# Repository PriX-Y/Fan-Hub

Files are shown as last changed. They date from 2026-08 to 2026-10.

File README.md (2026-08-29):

# Fan-Hub
**RP2040 PWM Fan Controller for x4 fan**
Zrzut ekranu 2026-08-18 223545
i made becuse this summer in europa is so hot: 43c but i didt have fan what have enough control for me so i made that, becuse my so bad soldring skill i make this full THT

# Programs
**Kicad - 10.1**

**Autodesk Fusion**

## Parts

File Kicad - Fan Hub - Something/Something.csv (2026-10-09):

Id | Oznaczenie | Footprint | Liczba | Oznaczenie | Dostawca i numer artykułu
1 | A1 | raspberry_pi_pico_THT | 1 | Raspberry_Pi_Pico_THT
2 | C1, C6, C9 | C_Disc_D5.0mm_W2.5mm_P2.50mm | 3 | 0.1uF
3 | C2, C5, C8 | C_Disc_D5.0mm_W2.5mm_P2.50mm | 3 | 1uF
4 | C3, C4, C7 | C_Disc_D5.0mm_W2.5mm_P2.50mm | 3 | 10uF
5 | D1, D6 | D_DO-41_SOD81_P7.62mm_Horizontal | 2 | 1N5818
6 | D2, D3, D4, D5 | D_DO-35_SOD27_P7.62mm_Horizontal | 4 | 1N4148
7 | J1 | BarrelJack_SwitchcraftConxall_RAPC10U_Horizontal | 1 | Barrel_Jack
8 | L1 | L_Axial_L5.3mm_D2.2mm_P10.16mm_Horizontal_Vishay_IM-1 | 1 | 100uH
9 | M1, M2, M3, M4 | FanPinHeader_1x04_P2.54mm_Vertical | 4 | Fan_4pin
10 | R1, R2, R3 | R_Axial_DIN0207_L6.3mm_D2.5mm_P10.16mm_Horizontal | 3 | 100k
11 | R4, R5, R6, R7, R8, R9 | R_Axial_DIN0207_L6.3mm_D2.5mm_P10.16mm_Horizontal | 6 | 10k
12 | SW5, SW6, SW7, SW8 | RotaryEncoder_Bourns_Horizontal_PEC12R-2x17F-Sxxxx | 4 | RotaryEncoder_Switch
13 | U1 | DIP-8_W7.62mm | 1 | ADP1108AN-12
14 | U2 | Converter_DCDC_TRACO_TSR-1_THT | 1 | TSR_1-24150
15 | U3 | ER_OLEDM0.91_1x-I2C | 1 | ER_OLEDM0.91_1x-I2C
16 | U4 | TO-92_Inline | 1 | LM35-LP

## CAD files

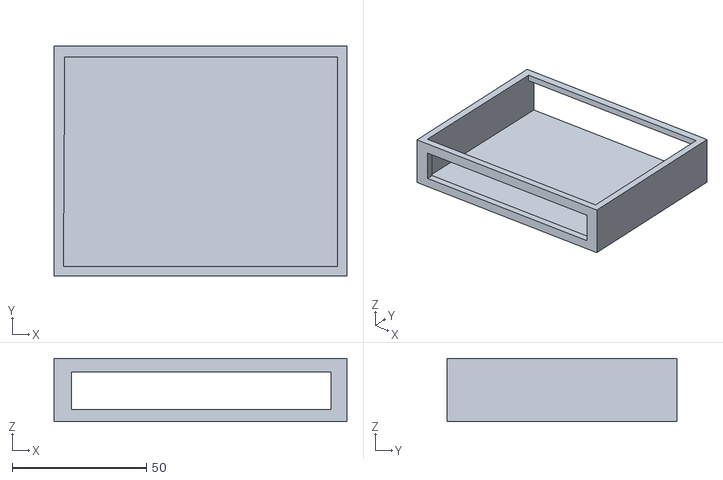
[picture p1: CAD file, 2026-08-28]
Case/HUB-CASE-DOWN.stl
109.0 x 85.5 x 23.5

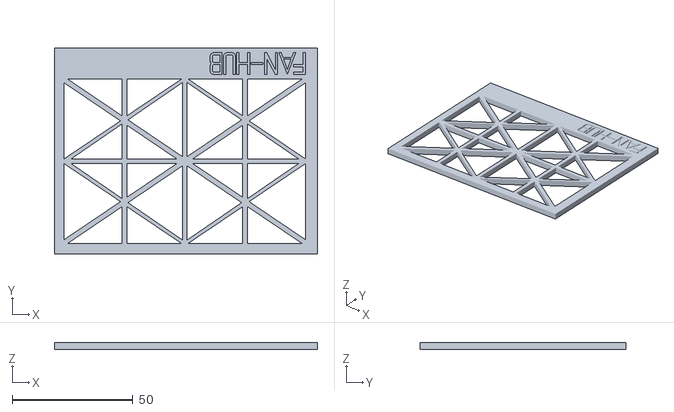
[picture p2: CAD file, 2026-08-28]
Case/HUB-CASE-TOP.stl
109.0 x 85.5 x 3.00

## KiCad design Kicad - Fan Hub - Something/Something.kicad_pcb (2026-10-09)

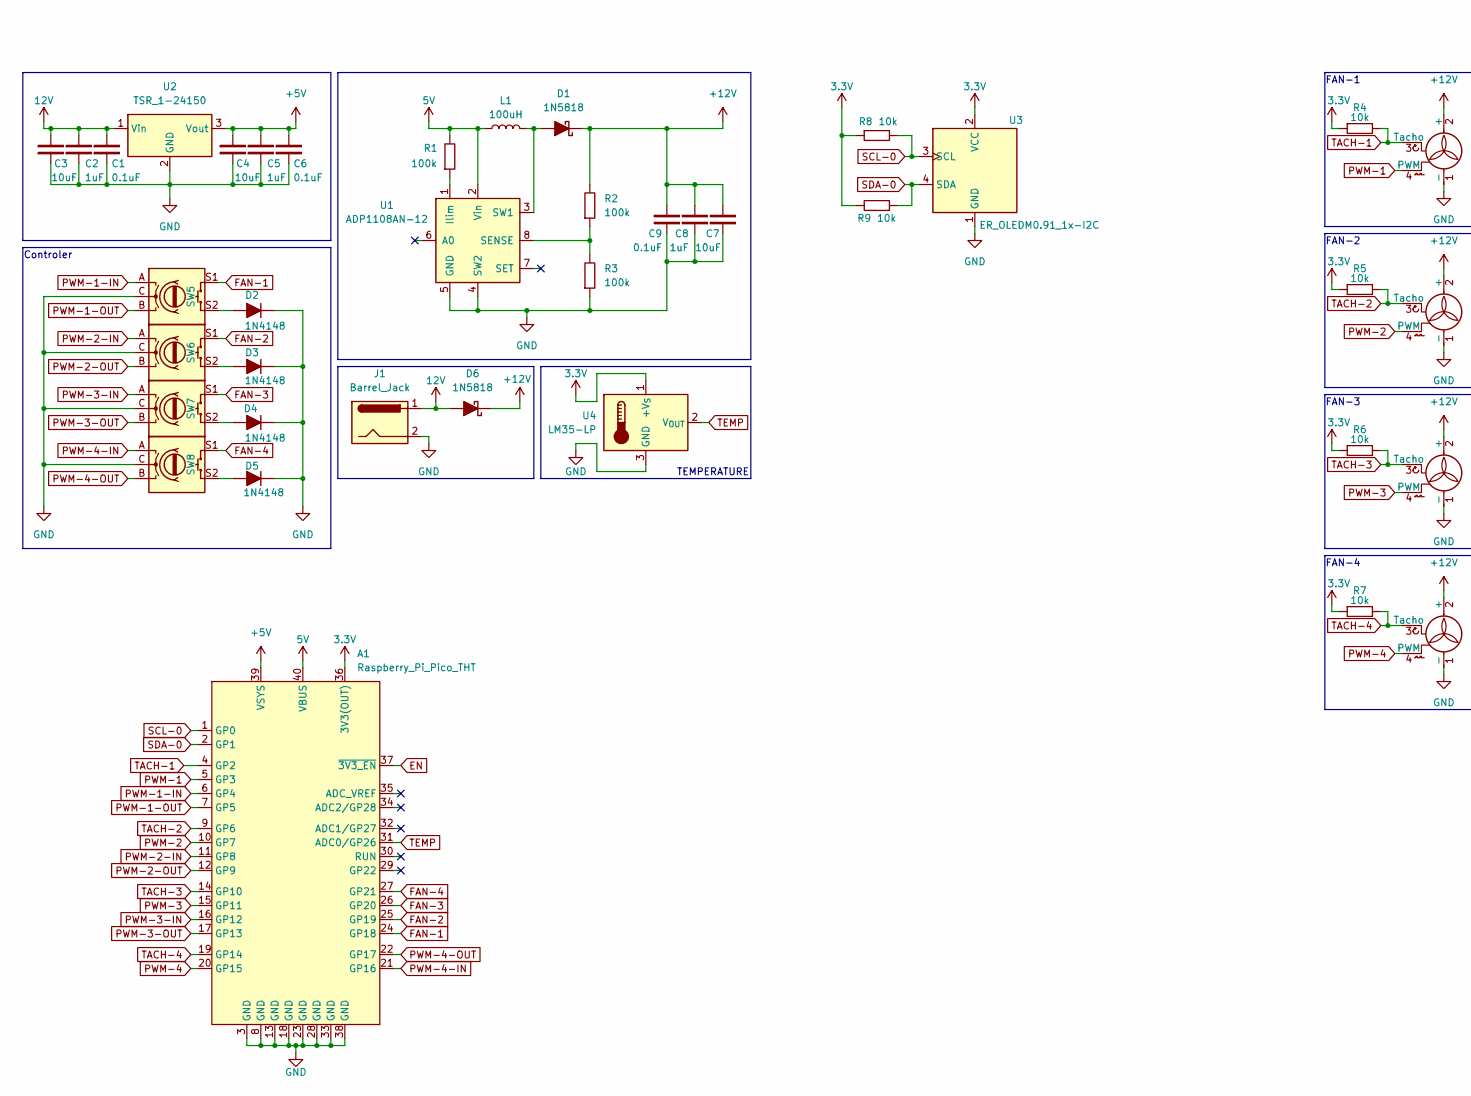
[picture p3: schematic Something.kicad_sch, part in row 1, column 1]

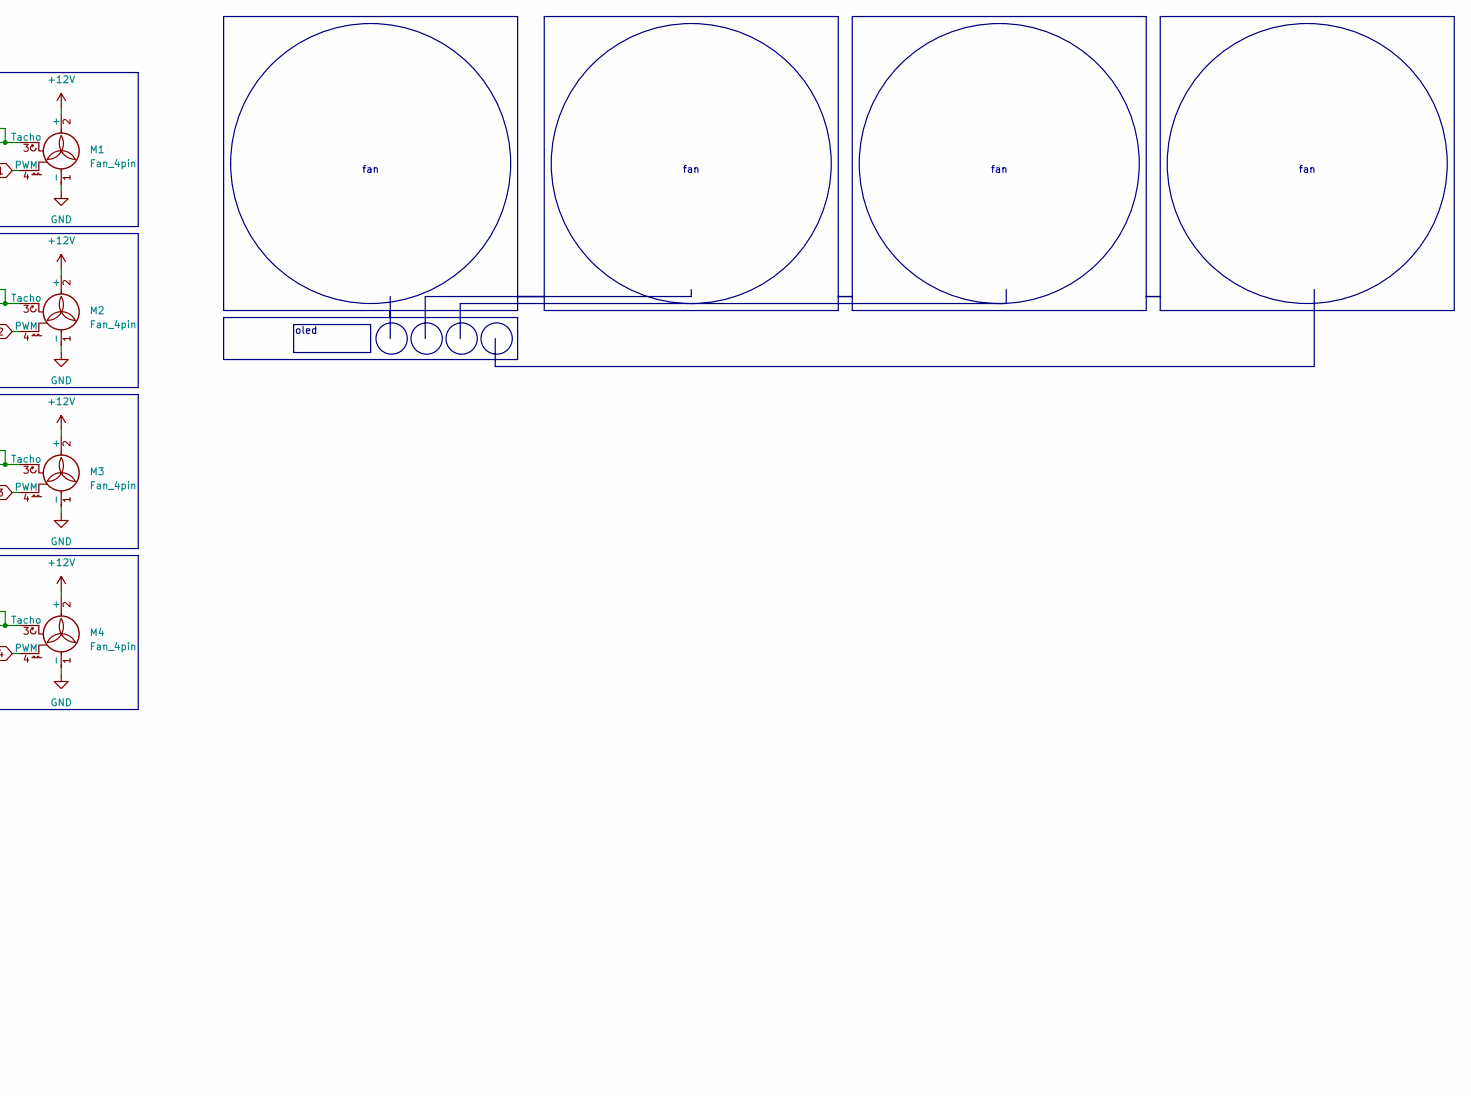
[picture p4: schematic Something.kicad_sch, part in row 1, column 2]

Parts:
A1: Raspberry_Pi_Pico_THT; raspberry_pi_pico_THT
C1, C6, C9: 0.1uF; C_Disc_D5.0mm_W2.5mm_P2.50mm
C2, C5, C8: 1uF; C_Disc_D5.0mm_W2.5mm_P2.50mm
C3, C4, C7: 10uF; C_Disc_D5.0mm_W2.5mm_P2.50mm
D1, D6: 1N5818; D_DO-41_SOD81_P7.62mm_Horizontal
D2, D3, D4, D5: 1N4148; D_DO-35_SOD27_P7.62mm_Horizontal
J1: Barrel_Jack; BarrelJack_SwitchcraftConxall_RAPC10U_Horizontal
L1: 100uH; L_Axial_L5.3mm_D2.2mm_P10.16mm_Horizontal_Vishay_IM-1
M1, M2, M3, M4: Fan_4pin; FanPinHeader_1x04_P2.54mm_Vertical
R1, R2, R3: 100k; R_Axial_DIN0207_L6.3mm_D2.5mm_P10.16mm_Horizontal
R4, R5, R6, R7, R8, R9: 10k; R_Axial_DIN0207_L6.3mm_D2.5mm_P10.16mm_Horizontal
SW5, SW6, SW7, SW8: RotaryEncoder_Switch; RotaryEncoder_Bourns_Horizontal_PEC12R-2x17F-Sxxxx
U1: ADP1108AN-12; DIP-8_W7.62mm
U2: TSR_1-24150; Converter_DCDC_TRACO_TSR-1_THT
U3: ER_OLEDM0.91_1x-I2C
U4: LM35-LP; TO-92_Inline

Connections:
3.3V: A1.36 (3V3(OUT)), R4.1, R5.1, R6.1, R7.1, R8.1, R9.2, U3.2 (VCC), U4.1 (+V_{S})
5V: A1.40 (VBUS), L1.1, R1.2, U1.2 (Vin)
12V: C1.2, C2.2, C3.2, D6.2 (A), J1.1, U2.1 (Vin)
+5V: A1.39 (VSYS), C4.2, C5.2, C6.2, U2.3 (Vout)
+12V: C7.2, C8.2, C9.2, D1.1 (K), D6.1 (K), M1.2 (+), M2.2 (+), M3.2 (+), M4.2 (+), R2.2
EN: A1.37 (~3V3_EN)
FAN-1: A1.24 (GP18), SW5.S1
FAN-2: A1.25 (GP19), SW6.S1
FAN-3: A1.26 (GP20), SW7.S1
FAN-4: A1.27 (GP21), SW8.S1
GND: A1.3 (GND), A1.8 (GND), A1.13 (GND), A1.18 (GND), A1.23 (GND), A1.28 (GND), A1.33 (GND), A1.38 (GND), C1.1, C2.1, C3.1, C4.1, C5.1, C6.1, C7.1, C8.1, C9.1, D2.1 (K), D3.1 (K), D4.1 (K), D5.1 (K), J1.2, M1.1 (-), M2.1 (-), M3.1 (-), M4.1 (-), R3.1, SW5.C, SW5.SH, SW6.C, SW7.C, SW8.C, U1.4 (SW2), U1.5 (GND), U2.2 (GND), U3.1 (GND), U4.3 (GND)
unnamed: D1.2 (A), L1.2, U1.3 (SW1)
unnamed: D2.2 (A), SW5.S2
unnamed: D3.2 (A), SW6.S2
unnamed: D4.2 (A), SW7.S2
unnamed: D5.2 (A), SW8.S2
unnamed: R1.1, U1.1 (Ilim)
unnamed: R2.1, R3.2, U1.8 (SENSE)
PWM-1: A1.5 (GP3), M1.4 (PWM)
PWM-1-IN: A1.6 (GP4), SW5.A
PWM-1-OUT: A1.7 (GP5), SW5.B
PWM-2: A1.10 (GP7), M2.4 (PWM)
PWM-2-IN: A1.11 (GP8), SW6.A
PWM-2-OUT: A1.12 (GP9), SW6.B
PWM-3: A1.15 (GP11), M3.4 (PWM)
PWM-3-IN: A1.16 (GP12), SW7.A
PWM-3-OUT: A1.17 (GP13), SW7.B
PWM-4: A1.20 (GP15), M4.4 (PWM)
PWM-4-IN: A1.21 (GP16), SW8.A
PWM-4-OUT: A1.22 (GP17), SW8.B
SCL-0: A1.1 (GP0), R8.2, U3.3 (SCL)
SDA-0: A1.2 (GP1), R9.1, U3.4 (SDA)
TACH-1: A1.4 (GP2), M1.3 (Tacho), R4.2
TACH-2: A1.9 (GP6), M2.3 (Tacho), R5.2
TACH-3: A1.14 (GP10), M3.3 (Tacho), R6.2
TACH-4: A1.19 (GP14), M4.3 (Tacho), R7.2
TEMP: A1.31 (ADC0/GP26), U4.2 (V_{OUT})

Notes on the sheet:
fan
Controler
FAN-4
FAN-3
TEMPERATURE
oled
FAN-1
FAN-2

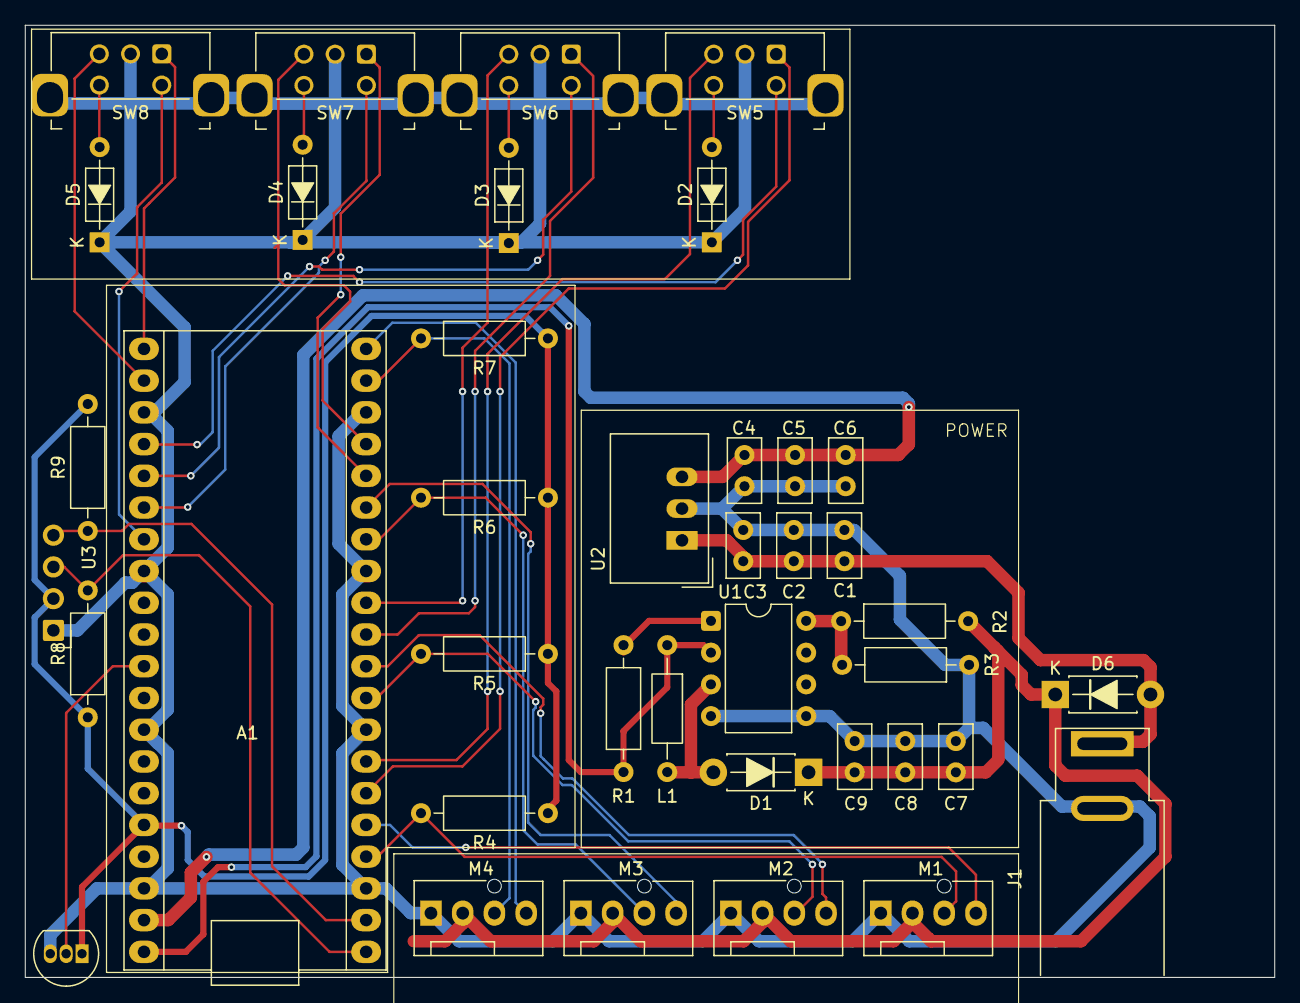
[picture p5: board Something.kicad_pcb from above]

Board: 2 copper layers, 100.0 x 76.2 mm, 39 parts (0 on the bottom side), 36 nets.

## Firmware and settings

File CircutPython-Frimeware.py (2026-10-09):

import framebuf
import time
from machine import ADC, I2C, Pin, PWM


SET_CONTRAST = 0x81
SET_ENTIRE_ON = 0xA4
SET_NORM_INV = 0xA6
SET_DISP = 0xAE
SET_MEM_ADDR = 0x20
SET_COL_ADDR = 0x21
SET_PAGE_ADDR = 0x22
SET_DISP_START_LINE = 0x40
SET_SEG_REMAP = 0xA0
SET_MUX_RATIO = 0xA8
SET_COM_OUT_DIR = 0xC0
SET_DISP_OFFSET = 0xD3
SET_COM_PIN_CFG = 0xDA
SET_DISP_CLK_DIV = 0xD5
SET_PRECHARGE = 0xD9
SET_VCOM_DESEL = 0xDB
SET_CHARGE_PUMP = 0x8D


class SSD1306_I2C(framebuf.FrameBuffer):
    def __init__(self, width, height, i2c, addr=0x3C):
        self.width = width
        self.height = height
        self.i2c = i2c
        self.addr = addr
        self.buffer = bytearray(self.width * self.height // 8)
        super().__init__(self.buffer, self.width, self.height, framebuf.MONO_VLSB)
        self.init_display()

    def write_cmd(self, cmd):
        self.i2c.writeto(self.addr, bytes([0x00, cmd]))

    def init_display(self):
        for cmd in (
            SET_DISP | 0x00,
            SET_MEM_ADDR,
            0x00,
            SET_DISP_START_LINE | 0x00,
            SET_SEG_REMAP | 0x01,
            SET_MUX_RATIO,
            self.height - 1,
            SET_COM_OUT_DIR | 0x08,
            SET_DISP_OFFSET,
            0x00,
            SET_COM_PIN_CFG,
            0x02 if self.height == 32 else 0x12,
            SET_DISP_CLK_DIV,
            0x80,
            SET_PRECHARGE,
            0xF1,
            SET_VCOM_DESEL,
            0x30,
            SET_CONTRAST,
            0xFF,
            SET_ENTIRE_ON,
            SET_NORM_INV,
            SET_CHARGE_PUMP,
            0x14,
            SET_DISP | 0x01,
        ):
            self.write_cmd(cmd)

    def show(self):
        self.write_cmd(SET_COL_ADDR)
        self.write_cmd(0)
        self.write_cmd(self.width - 1)
        self.write_cmd(SET_PAGE_ADDR)
        self.write_cmd(0)
        self.write_cmd((self.height // 8) - 1)
        self.i2c.writeto(self.addr, b"\x40" + self.buffer)


class FanController:
    def __init__(self, fan_id, pwm_pin, tach_pin, initial_duty=50):
        self.fan_id = fan_id
        self.pwm = PWM(Pin(pwm_pin))
        self.pwm.freq(25000)

        self.duty_percent = initial_duty
        self._update_pwm()

        self.tach_pin = Pin(tach_pin, Pin.IN, Pin.PULL_UP)
        self.rpm_count = 0
        self.last_rpm_time = time.ticks_ms()
        self.tach_pin.irq(trigger=Pin.IRQ_RISING | Pin.IRQ_FALLING, handler=self._tach_isr)

    def _update_pwm(self):
        duty_u16 = int((self.duty_percent / 100.0) * 65535)
        self.pwm.duty_u16(duty_u16)

    def _tach_isr(self, pin):
        if pin.value():
            self.rpm_count += 1

    def get_rpm(self):
        now = time.ticks_ms()
        elapsed_ms = time.ticks_diff(now, self.last_rpm_time)
        if elapsed_ms >= 1000:
            rpm = (self.rpm_count * 60000) // (elapsed_ms * 2)
            self.rpm_count = 0
            self.last_rpm_time = now
            return rpm
        return 0

    def increase_duty(self, step=5):
        self.duty_percent = min(100, self.duty_percent + step)
        self._update_pwm()

    def decrease_duty(self, step=5):
        self.duty_percent = max(0, self.duty_percent - step)
        self._update_pwm()


class Encoder:
    def __init__(self, pin_a, pin_b, controller):
        self.pin_a = Pin(pin_a, Pin.IN, Pin.PULL_UP)
        self.pin_b = Pin(pin_b, Pin.IN, Pin.PULL_UP)
        self.controller = controller
        self.last_a = self.pin_a.value()
        self.pin_a.irq(trigger=Pin.IRQ_RISING | Pin.IRQ_FALLING, handler=self._encoder_isr)

    def _encoder_isr(self, pin):
        current_a = self.pin_a.value()
        if current_a != self.last_a:
            if self.pin_b.value() != current_a:
                self.controller.increase_duty(5)
            else:
                self.controller.decrease_duty(5)
            self.last_a = current_a


i2c = I2C(0, scl=Pin(0), sda=Pin(1), freq=400000)
oled = SSD1306_I2C(128, 32, i2c)

temp_sensor = ADC(Pin(26))

FANS_CONFIG = [
    (1, 3, 2),
    (2, 7, 6),
    (3, 11, 10),
    (4, 15, 14),
]

controllers = [
    FanController(cfg[0], cfg[1], cfg[2]) for cfg in FANS_CONFIG
]

ENCODER_CONFIG = [
    (4, 5, controllers[0]),
    (8, 9, controllers[1]),
    (12, 13, controllers[2]),
    (16, 17, controllers[3]),
]

encoders = [
    Encoder(cfg[0], cfg[1], cfg[2]) for cfg in ENCODER_CONFIG
]


def read_temperature():
    raw_adc = temp_sensor.read_u16()
    voltage = (raw_adc / 65535.0) * 3.3
    temperature = voltage * 100.0
    return temperature


last_temp_update = 0
last_display_update = 0
temp_c = 0.0

while True:
    now = time.ticks_ms()

    if time.ticks_diff(now, last_temp_update) >= 100:
        last_temp_update = now
        temp_c = read_temperature()

    if time.ticks_diff(now, last_display_update) >= 200:
        last_display_update = now
        oled.fill(0)
        oled.text("TEMP: {:.1f} C".format(temp_c), 0, 0)

        f1_val = controllers[0].duty_percent
        f2_val = controllers[1].duty_percent
        oled.text("F1:{:3d}%  F2:{:3d}%".format(f1_val, f2_val), 0, 12)

        f3_val = controllers[2].duty_percent
        f4_val = controllers[3].duty_percent
        oled.text("F3:{:3d}%  F4:{:3d}%".format(f3_val, f4_val), 0, 24)

        oled.show()

    time.sleep(0.01)
